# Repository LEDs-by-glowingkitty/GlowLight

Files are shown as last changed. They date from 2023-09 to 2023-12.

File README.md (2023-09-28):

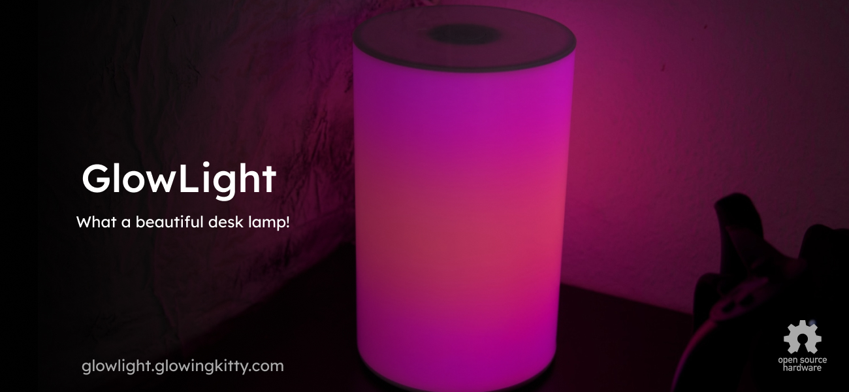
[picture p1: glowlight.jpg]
GlowLight


## What is this project?

A compact desk lamp that glows smoothly from all sides. Perfect for setting a relaxed mood at home, or to use it as a party light.

## Links

- [Shop](https://shop.glowingkitty.com/products/glowlight)
- [More details](https://glowingkitty.com/glowlight)
- [Tech specs](https://glowingkitty.com/glowlight/specs)
- [FAQ](https://glowingkitty.com/glowlight/faq)
- [Documents](https://glowingkitty.com/glowlight/docs)
- [3D files](https://glowingkitty.com/glowlight/3d)
- [PCB files](https://glowingkitty.com/glowlight/pcb)

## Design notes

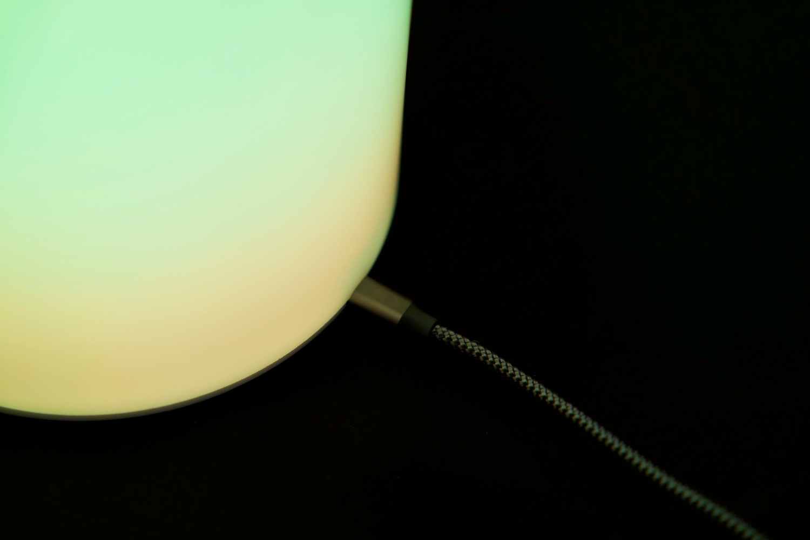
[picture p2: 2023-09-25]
images/glowlight_usbc.jpg

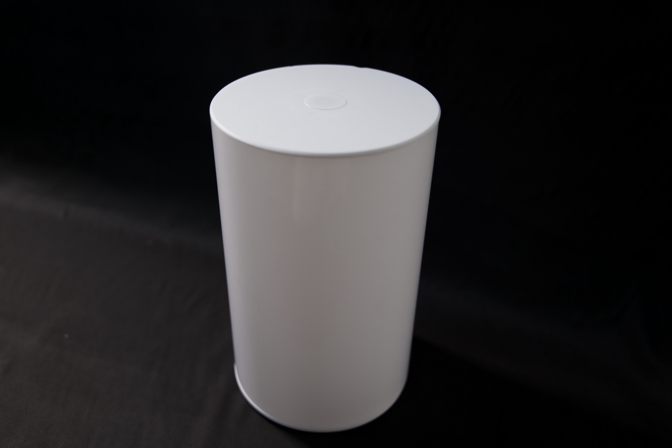
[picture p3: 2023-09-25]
images/glowlight_lamp_off.jpg

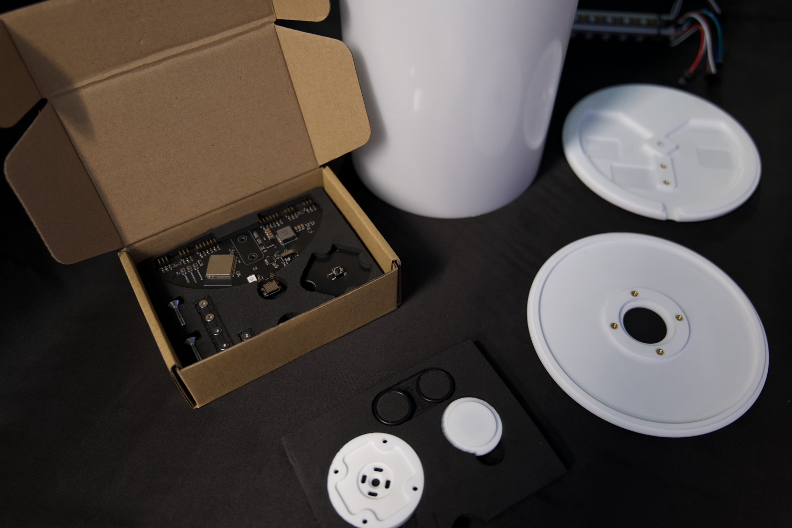
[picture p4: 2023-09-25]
images/glowlight_diy_kit.jpg

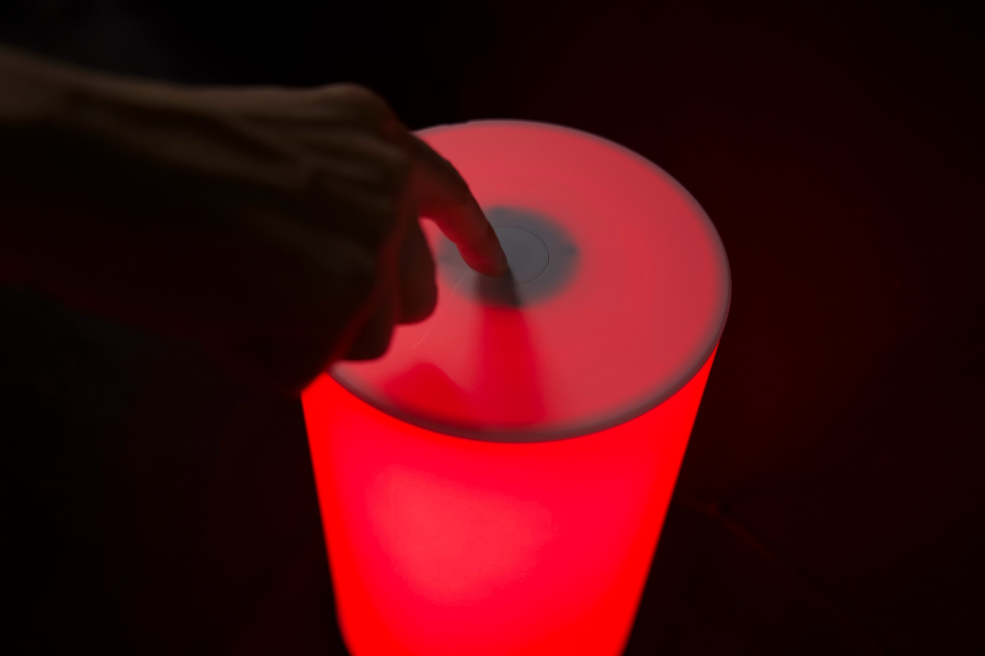
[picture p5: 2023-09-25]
images/glowlight_press_button.jpg

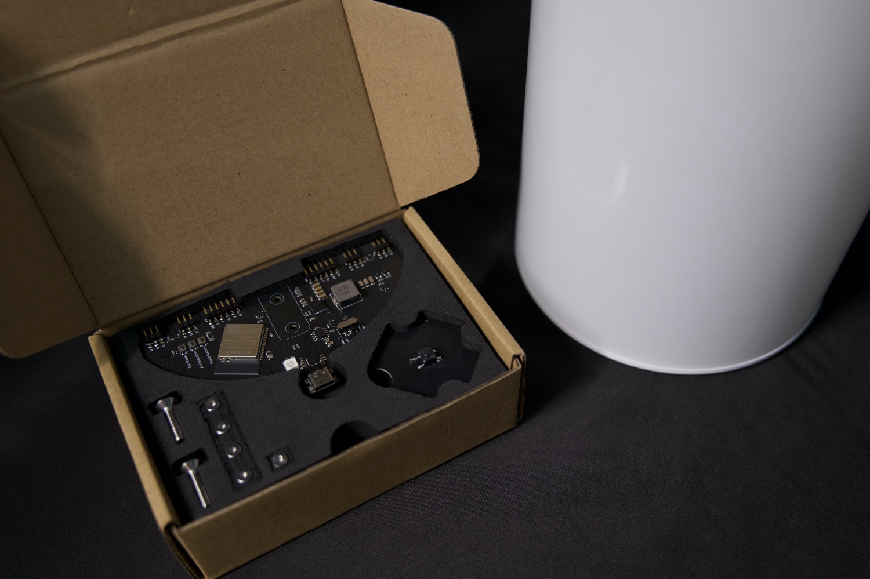
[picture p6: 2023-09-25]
images/glowlight_you_own_it.jpg

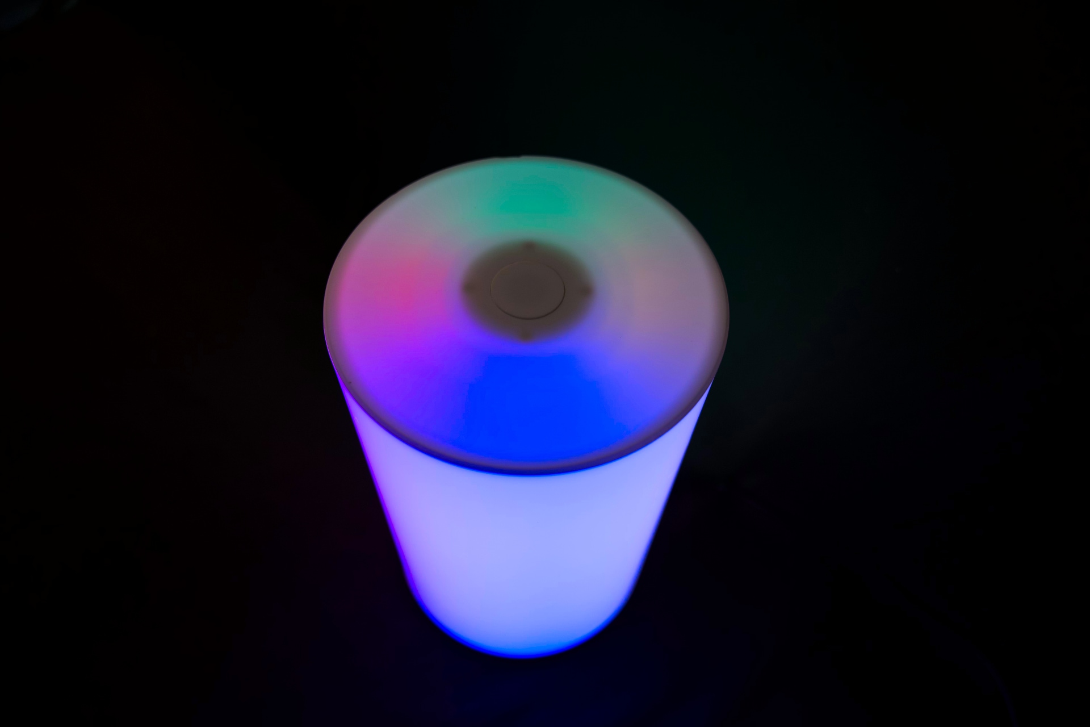
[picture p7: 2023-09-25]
images/glowlight_full_color.jpg

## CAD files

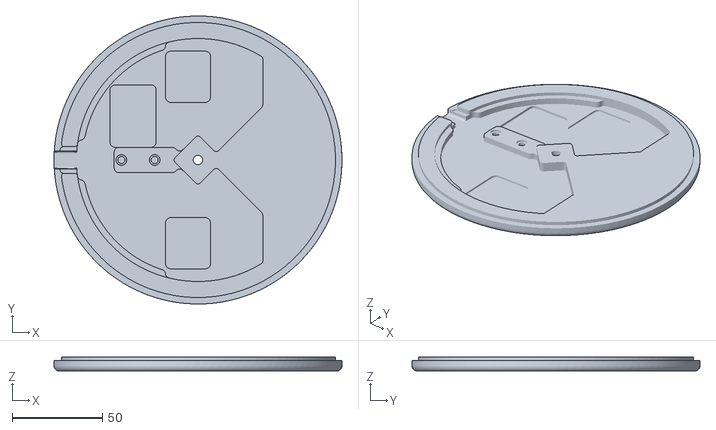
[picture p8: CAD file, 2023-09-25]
3D files/case/bottom_case.stl
160.0 x 160.0 x 8.00

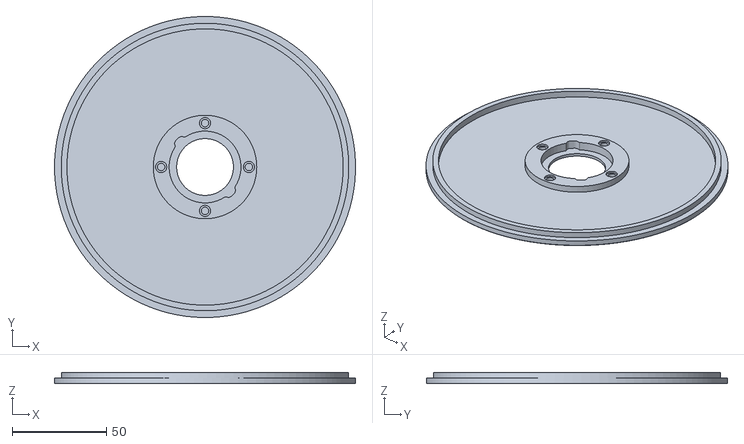
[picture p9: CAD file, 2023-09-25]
3D files/case/top_acrylic_part.stl
160.0 x 160.0 x 6.00

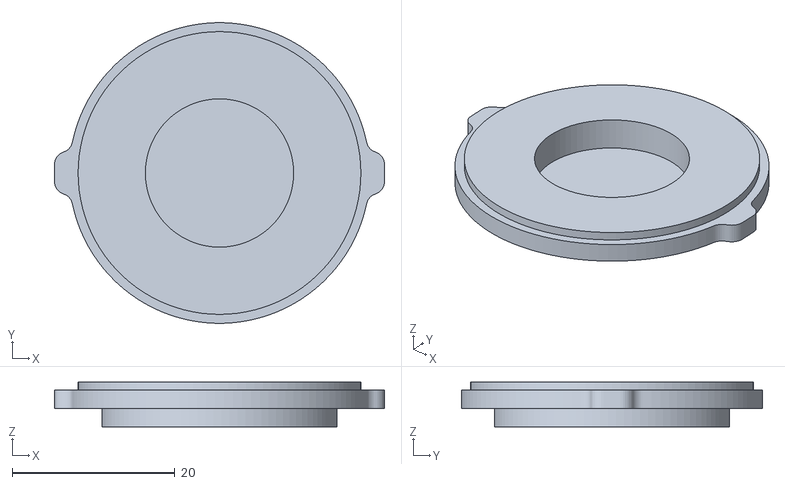
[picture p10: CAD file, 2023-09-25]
3D files/case/button.stl
40.5 x 36.9 x 5.50

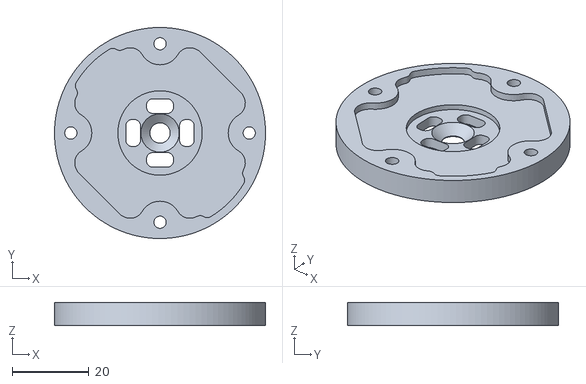
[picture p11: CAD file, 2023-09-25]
3D files/case/top_case_to_aluminum_connector.stl
55.0 x 55.0 x 6.00

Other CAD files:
3D files/step files/MainPCB.step
3D files/step files/GlowLight.step
3D files/case/top_acrylic_part_no_button.stl
3D files/step files/ButtonPCB.step

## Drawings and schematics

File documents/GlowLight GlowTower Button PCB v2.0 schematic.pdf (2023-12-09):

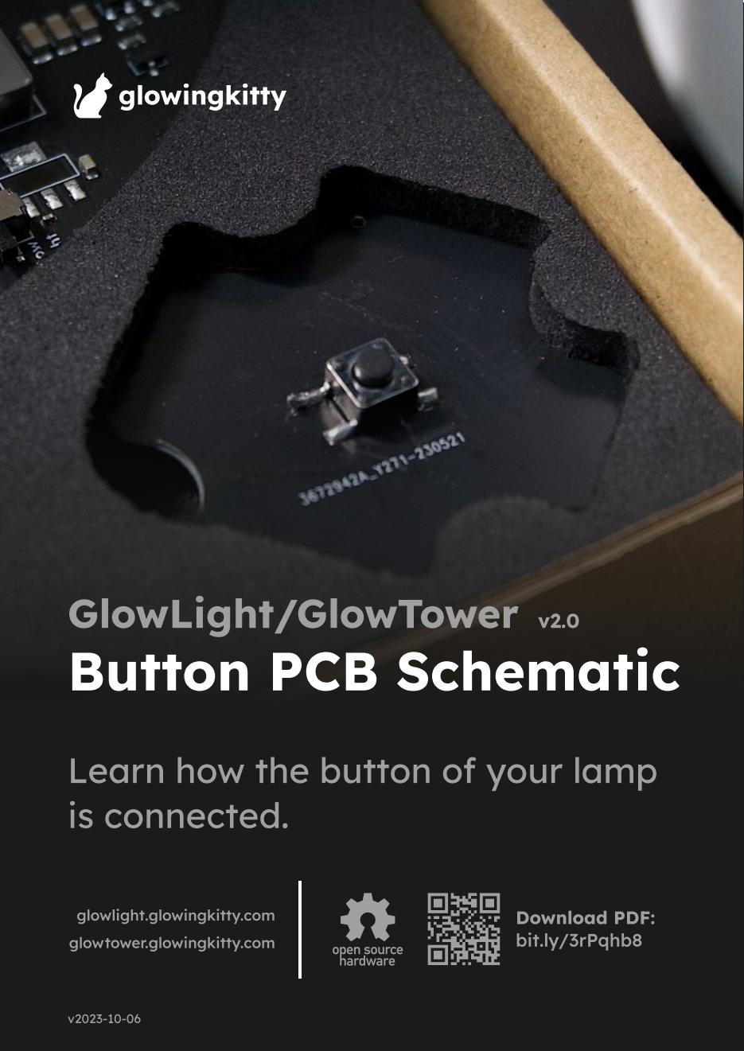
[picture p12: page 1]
is connected.; glowlight.glowingkitty.com; Download PDF:; bit.ly/3rPqhb8; glowingkitty

GlowLight/GlowTower v2.0
Button PCB Schematic

Learn how the button of your lamp

glowtower.glowingkitty.com

# Button PCB

# Schematic

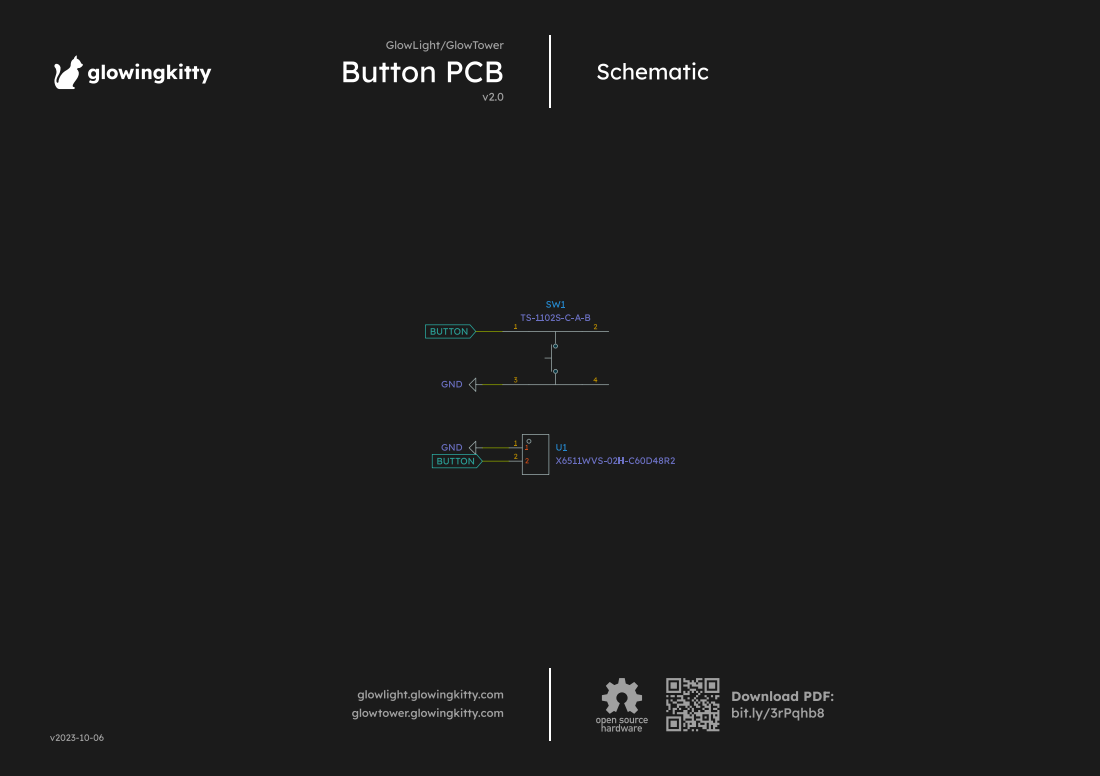
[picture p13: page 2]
GlowLight/GlowTower; glowlight.glowingkitty.com; Download PDF:; bit.ly/3rPqhb8; glowingkitty

glowtower.glowingkitty.com

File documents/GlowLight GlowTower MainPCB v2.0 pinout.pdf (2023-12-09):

# glowingkitty

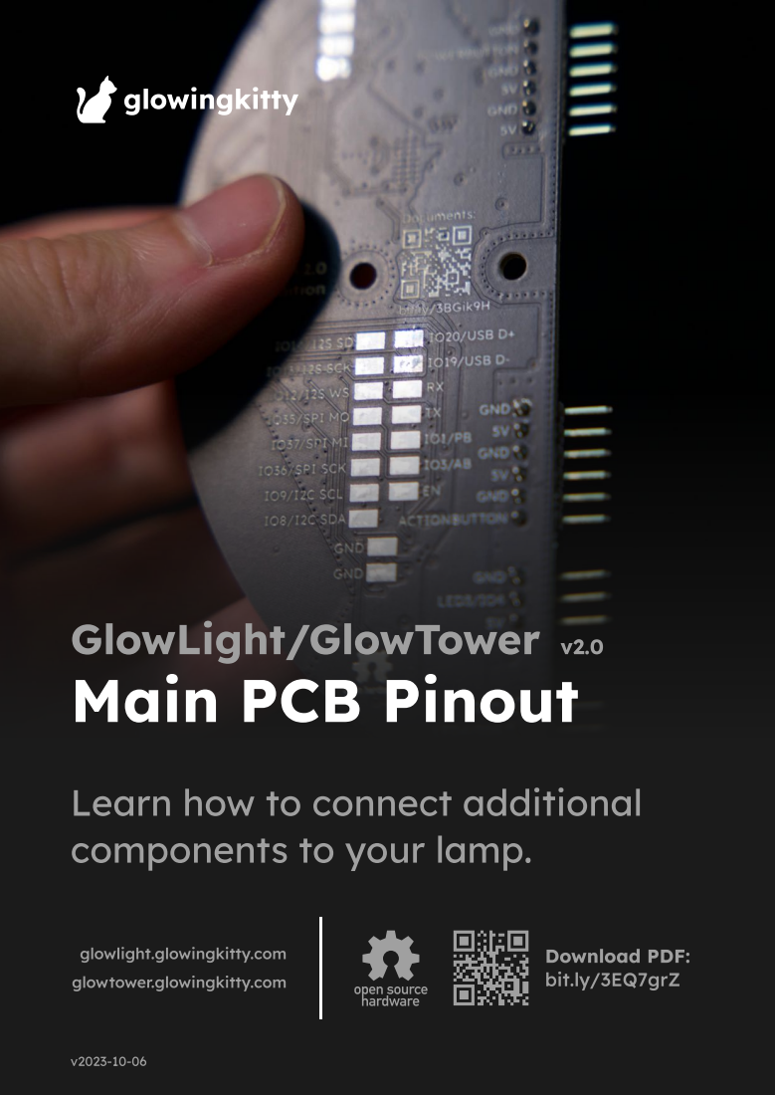
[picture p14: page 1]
glowlight.glowingkitty.com; Download PDF:; bit.ly/3EQ7grZ

GlowLight/GlowTower v2.0
Main PCB Pinout

Learn how to connect additional

components to your lamp.

glowtower.glowingkitty.com

# Main PCB

v2.0

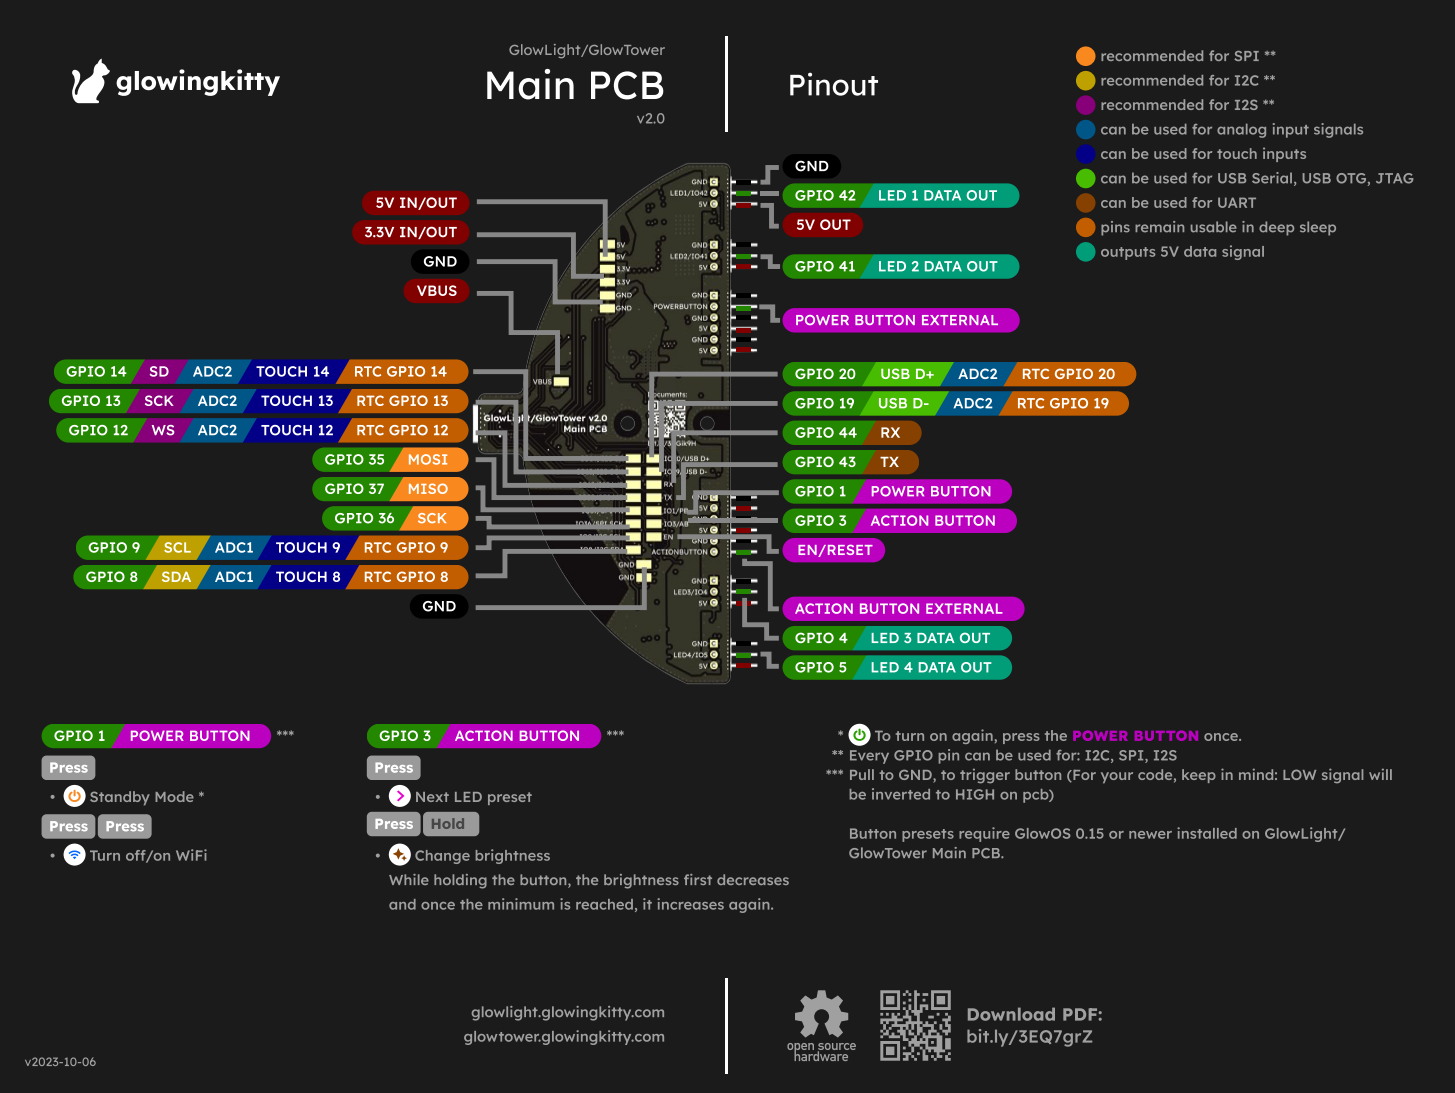
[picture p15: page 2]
recommended for I2C **; recommended for I2S **; GPIO 3; ACTION BUTTON; Next LED preseM; Change brightness; Press; Hold; GPIO 1; POWER BUTTON; Standby Mode n; Turn off/on WiFi; To turn on again, press the; once.; 5V IN/OUT; 3.3V IN/OUT; GND; VBUS; GPIO 14; ADC2; TOUCH 14; RTC GPIO 14; GPIO 13; SCK; TOUCH 13; RTC GPIO 13; GPIO 12; TOUCH 12; RTC GPIO 12; GPIO 35; MOSI; GPIO 37; MISO; GPIO 36; GPIO 9; SCL; ADC1; TOUCH 9; RTC GPIO 9; GPIO 8; SDA; TOUCH 8; RTC GPIO 8; GPIO 42; LED 1 DATA OUT; 5V OUT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

recommended for SPI **

can be used for analog input signals

can be used for touch inputs

can be used for USB Serial, USB OTG, JTAG

can be used for UART

pins remain usable in deep sleep

outputs 5V data signal

POWER BUTTON EXTERNAL

ACTION BUTTON EXTERNAL

Every GPIO pin can be used for: I2C, SPI, I2S
Pull to GND, to trigger button (For your code, keep in mind: LOW signal will
be inverted to HIGH on pcb)

Button presets require GlowOS 0.15 or newer installed on GlowLight/
GlowTower Main PCB.

While holding the button, the brightness first decreases

and once the minimum is reached, it increases again.

glowtower.glowingkitty.com

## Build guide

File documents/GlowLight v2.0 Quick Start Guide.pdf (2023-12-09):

# glowingkitty

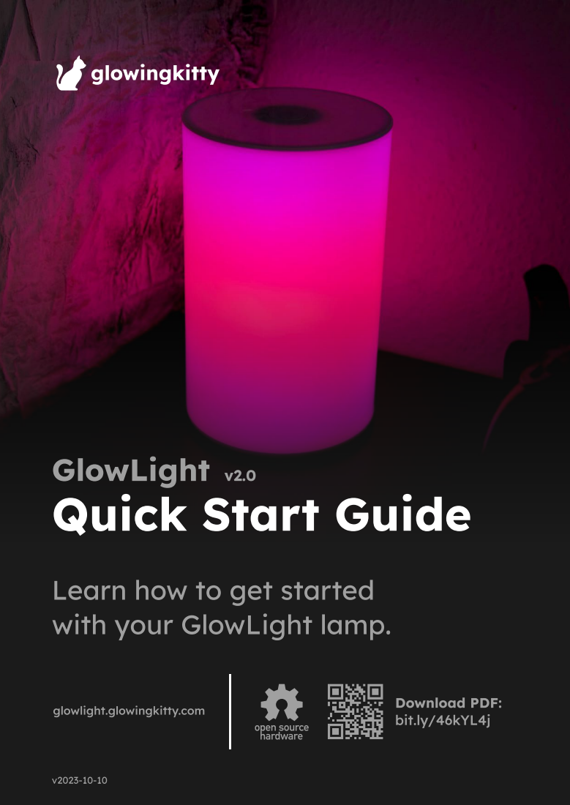
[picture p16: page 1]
glowlight.glowingkitty.com; Download PDF:; bit.ly/46kYL4j

GlowLight v2.0
Quick Start Guide

Learn how to get started
with your GlowLight lamp.

### Step 1:

# Connect to USB-C

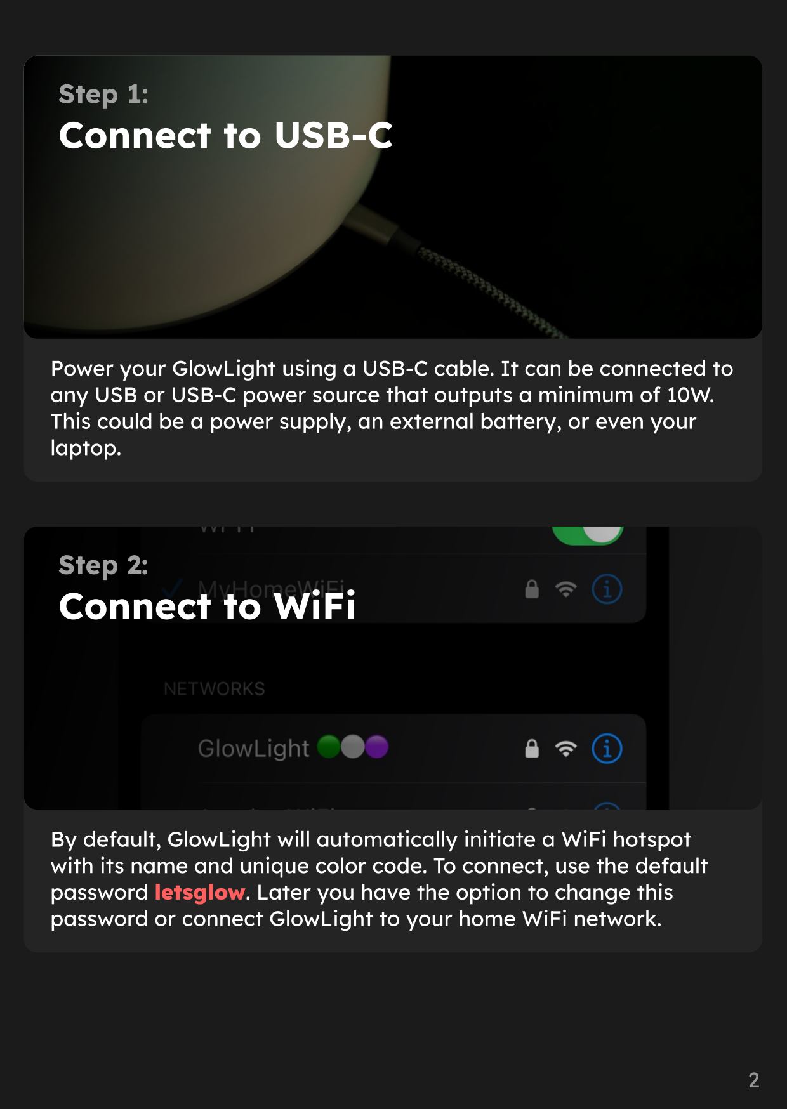
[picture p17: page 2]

Power your GlowLight using a USB-C cable. It can be connected to

any USB or USB-C power source that outputs a minimum of 10W.

This could be a power supply, an external battery, or even your

laptop.

### Step 2:

# Connect to WiFi

By default, GlowLight will automatically initiate a WiFi hotspot

with its name and unique color code. To connect, use the default

password | . Later you have the option to change this

password or connect GlowLight to your home WiFi network.

letsglow

## Step 3.0:

# GlowOS

GlowLight runs GlowOS, a customized version of the famous open-

source software WLED. GlowOS is equipped with over 100 LED

effects that can be applied to any segment of your GlowLight

LEDs. | These effects can be further personalized, offering nearly
limitless combinations. | Once you connect to your GlowLight lamp,

a popup should appear, with the control interface of GlowOS/

WLED. | If not, open your web browser and the URL | . http://4.3.2.1

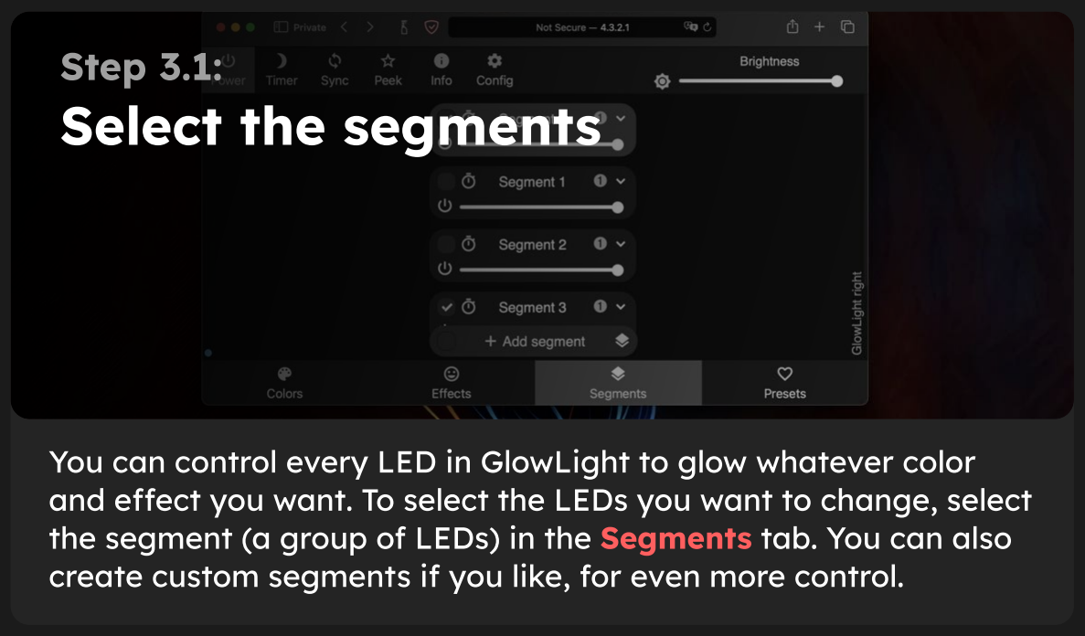
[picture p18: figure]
Step 3.1:; Select the segments; Segments

You can control every LED in GlowLight to glow whatever color

and effect you want. | To select the LEDs you want to change, select
the segment (a group of LEDs) in the | tab. | You can also

create custom segments if you like, for even more control.

# Step 3.2:

# Select the effect

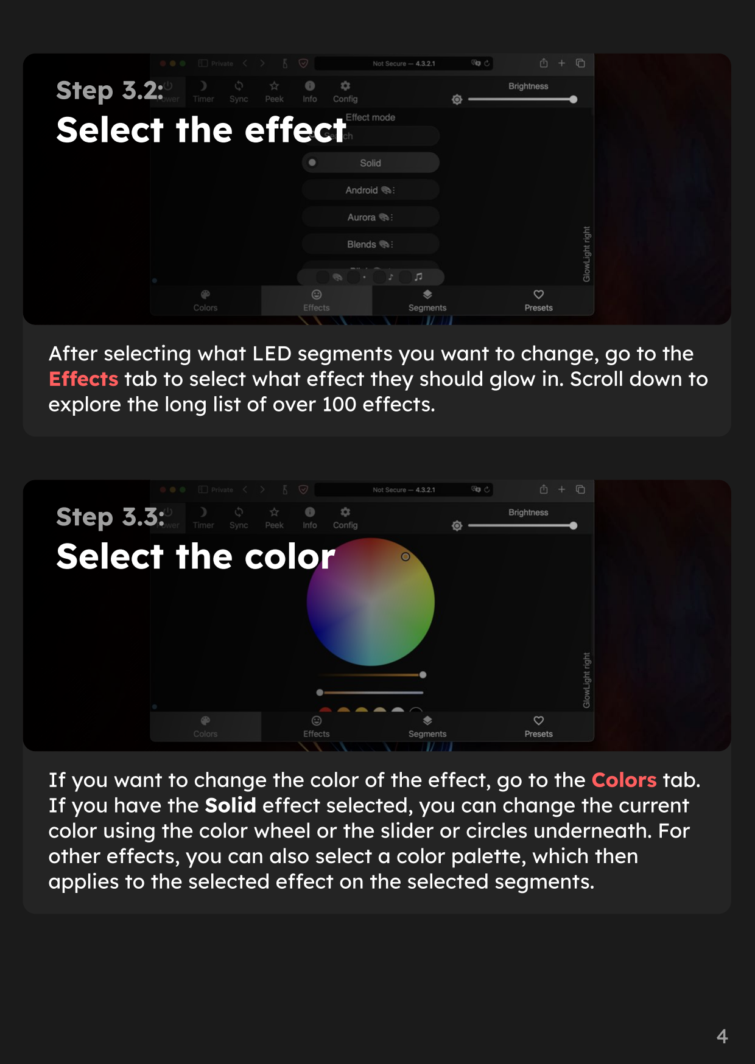
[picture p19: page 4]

## After selecting what LED segments you want to change, go to the tab to select what effect they should glow in. Scroll down to

explore the long list of over 100 effects.

## Effects

# Step 3.3:

# Select the color

If you want to change the color of the effect, go to the | tab.

## If you have the Solid effect selected, you can change the current color using the color wheel or the slider or circles underneath. For other effects, you can also select a color palette, which then

applies to the selected effect on the selected segments.

## Colors

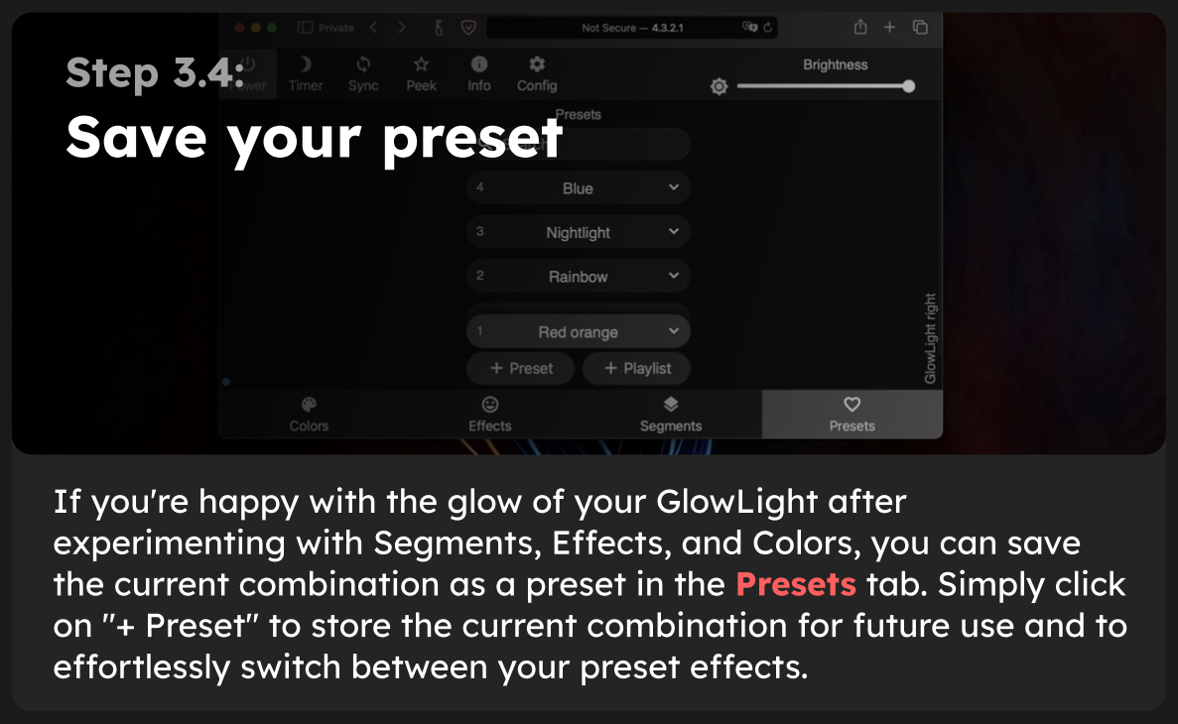
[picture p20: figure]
Step 3.4: Save your preset; Presets

## If you're happy with the glow of your GlowLight after experimenting with Segments, Effects, and Colors, you can save

the current combination as a preset in the | tab. Simply click

## on "+ Preset" to store the current combination for future use and to

effortlessly switch between your preset effects.

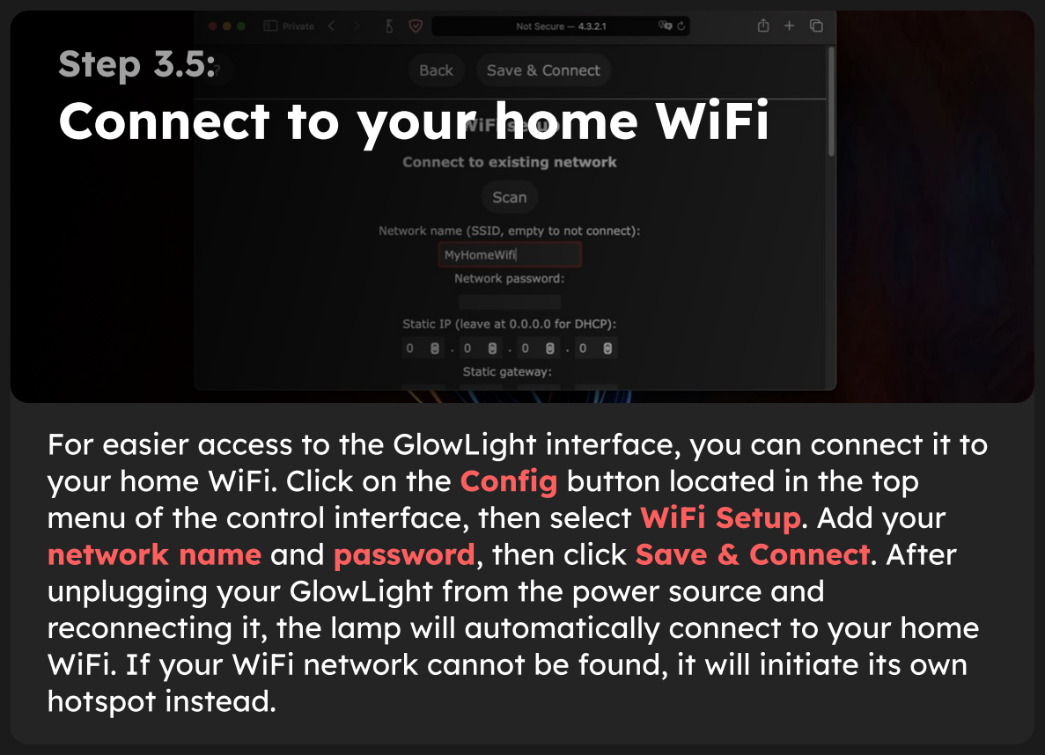
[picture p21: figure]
Step 3.5: Connect to your home WiFi; and; , then click; . After; hotspot instead.; Config; WiFi Setup; network name; password; Save & Connect

## For easier access to the GlowLight interface, you can connect it to

your home WiFi. Click on the | button located in the top
menu of the control interface, then select | . Add your

## unplugging your GlowLight from the power source and reconnecting it, the lamp will automatically connect to your home WiFi. If your WiFi network cannot be found, it will initiate its own

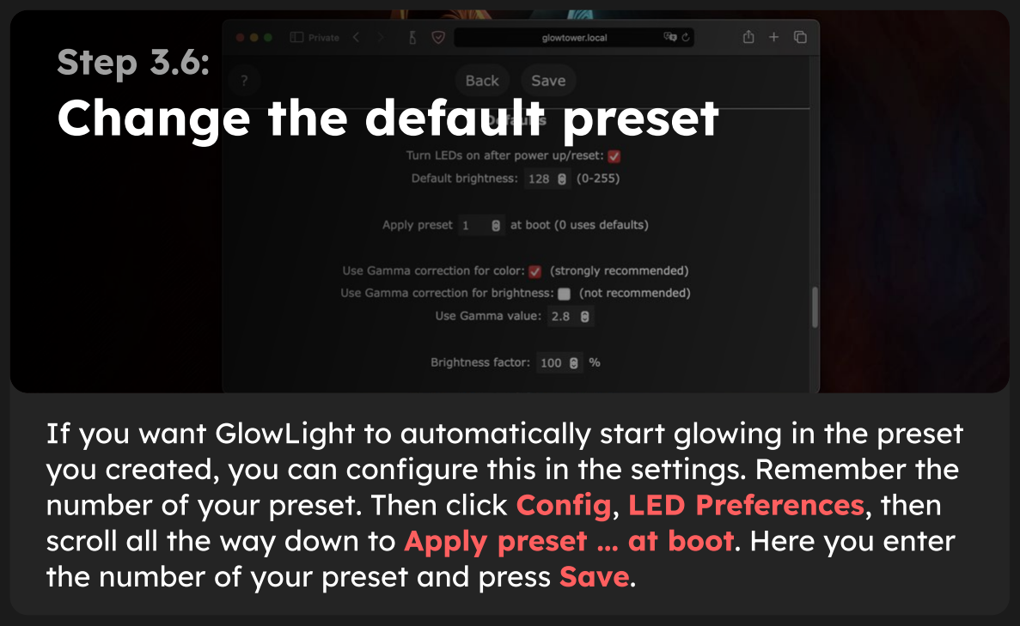
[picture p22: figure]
Step 3.6: Change the default preset; the number of your preset and press; Config LED Preferences; Apply preset ... at boot; Save

If you want GlowLight to automatically start glowing in the preset

you created, you can configure this in the settings. Remember the

number of your preset. Then click | , | , then
scroll all the way down to | | . Here you enter

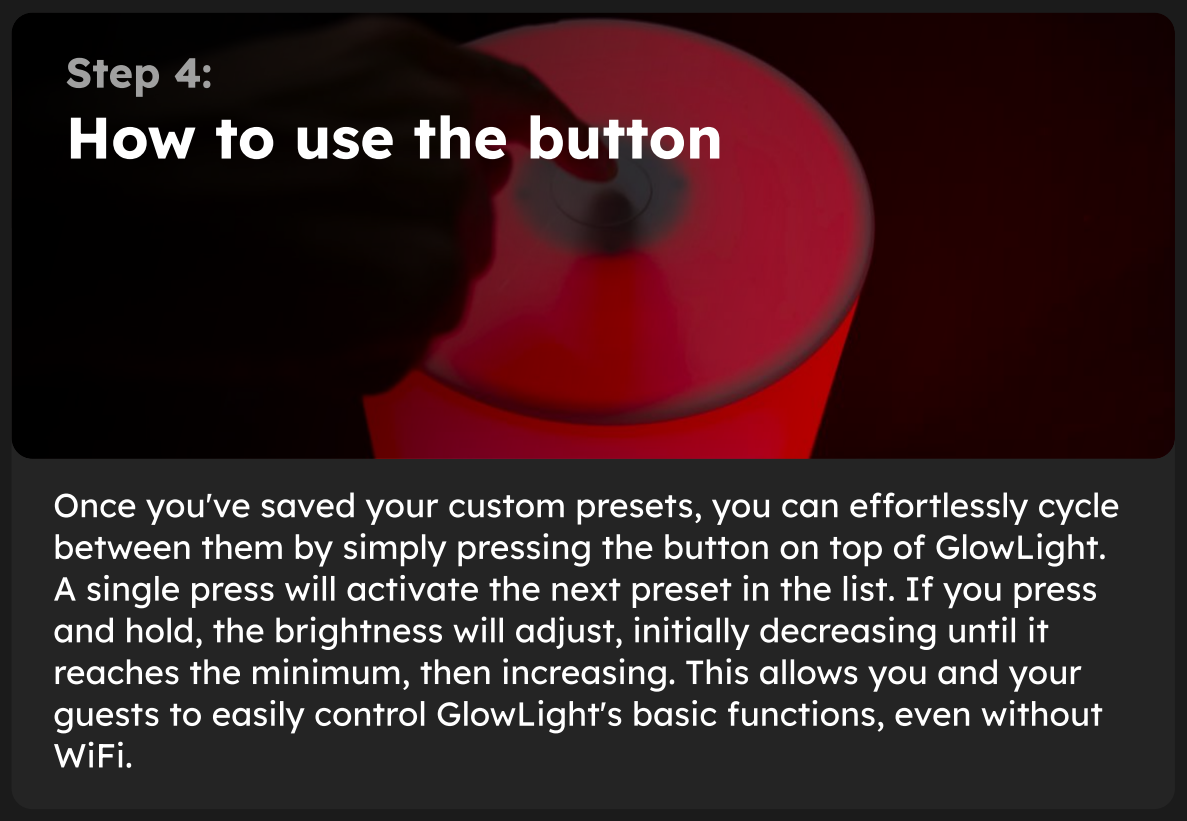
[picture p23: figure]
Step 4: How to use the button; WiFi.

Once you've saved your custom presets, you can effortlessly cycle

between them by simply pressing the button on top of GlowLight.

A single press will activate the next preset in the list. If you press and hold, the brightness will adjust, initially decreasing until it

reaches the minimum, then increasing. This allows you and your

guests to easily control GlowLight's basic functions, even without

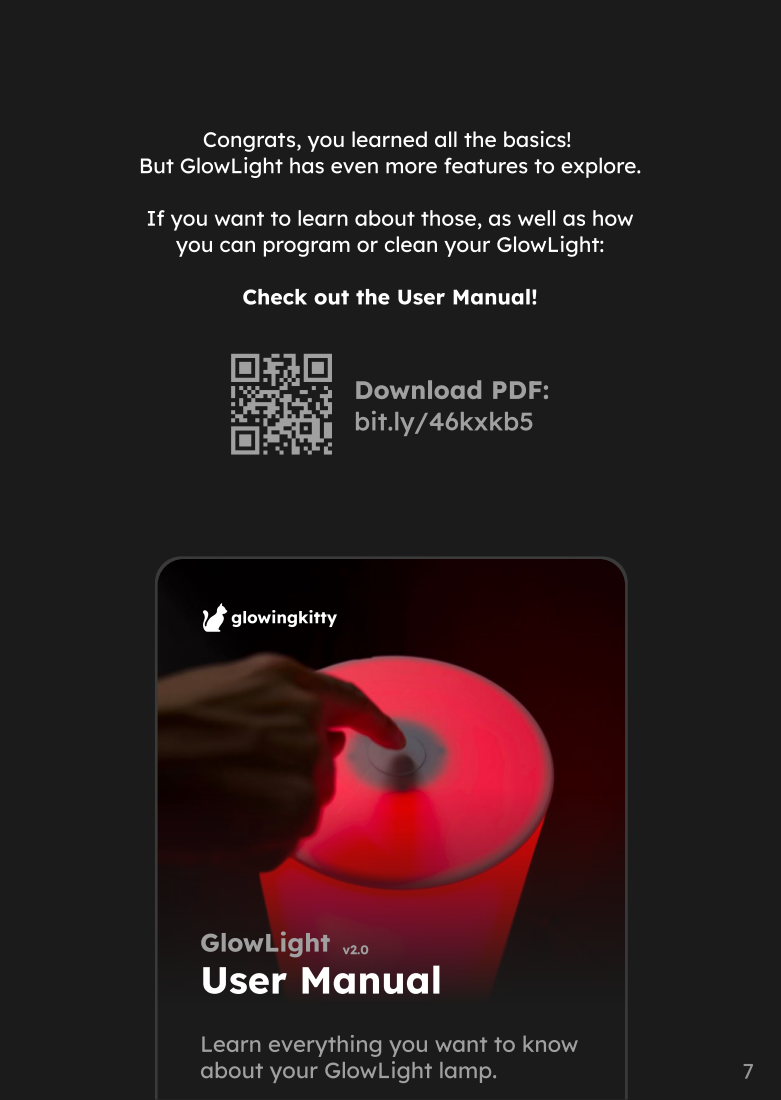
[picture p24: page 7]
Download PDF: bit.ly/46kxkb5; GlowLight v2.0 User Manual; glowingkitty

Congrats, you learned all the basics!

But GlowLight has even more features to explore.

If you want to learn about those, as well as how
you can program or clean your GlowLight:

Check out the User Manual!

Learn everything you want to know
about your GlowLight lamp.

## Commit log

2021-10-26 updated GlowLight design and started adding manual
    [bottom case.3mf, bottom cover.3mf, top case.3mf]
2021-11-06 made further improvements to case design
    [bottom case.3mf, bottom case.stl, bottom cover.3mf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]
2021-11-09 updated 3d model, shortened aluminium tube
    [bottom case.stl, top case.stl]
2021-11-09 fix description (shortened aluminium tube)
2021-11-16 fix wire connection image
2021-11-22 improved fit for esp32 and wago connectors
    [bottom case.stl]
2021-11-22 update case
2021-12-11 fixed wrong analog pin
2021-12-18 replaced USB-C board with USB-C PD board
    [bottom case.stl, bottom cover.stl]
2022-03-17 updated case, based on GlowTower PCB design
    [aluminium tube blocker.stl, bottom case.stl, bottom cover.stl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]
2022-03-17 added link to 3d models and pcb files
2022-03-26 added 3d printed case files
2022-05-01 updated 3d printed case
    [aluminium tube blocker.stl, bottom cover.stl, bottom_case.stl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]
2022-05-10 updated 3d model
    [bottom cover.stl, bottom_case.stl]
2022-06-21 updated 3D models
    [bottom cover.stl, bottom_case.stl, bottom_cover.stl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]
2022-06-30 updated case
    [bottom_case.stl, top_case.stl]
2022-07-04 added schottky diode to protect usb-c port
2022-07-05 added second schottky diode for reduced heat
2022-07-07 increased hole size for screw insert
    [top_case.stl]
2022-08-24 updated 3d prints and added silicone mold parts
    [bottom_case.stl, bottom_cover.stl, case A.stl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]
2022-12-03 added pinout and uodated 3d printed parts
    [bottom_case.stl, bottom_cover.stl, button open mold.stl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]
2023-02-16 added scripts, updated case mold parts
    [bottom wood cover.dxf, bottom_case.stl, bottom_cover.stl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]
2023-02-22 added blender file
    [GlowLight.blend]
2023-03-01 added json files with files overview
    [helper a.stl, helper b.stl]
2023-03-01 updated 3d models, cleaned repo, updated jsons
    [ButtonPCB.step, GlowLight.step, MainPCB.step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]
2023-03-07 updated pcb files
2023-05-19 updated pcb design
    [Button PCB.kicad_pcb, Button PCB.kicad_sch, MainPCB.kicad_sch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]
2023-07-12 update pcb design
    [MainPCB.kicad_sch]
2023-07-12 added schematic
2023-09-25 added pinout for main pcb 2.0 and new photos
    [MainPCB.kicad_sch]
2023-09-25 added pinout for main pcb v2.0
2023-09-25 updated 3d models, removed old images
    [GlowLight.blend, GlowLight.step, MainPCB.step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]
2023-09-25 removed not needed files
    [bottom wood cover.dxf, button open mold.stl, case A.stl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]
2023-09-25 updated 3d model of bottom case
    [bottom_case.stl]
2023-09-25 added zips for new pcb files
    [TouchPad PCB.kicad_pcb, TouchPad PCB.kicad_sch]
2023-09-26 added button pcb schematic
2023-09-26 added pcb files and schematics
2023-12-09 added new documents
    [MainPCB.kicad_sch]
